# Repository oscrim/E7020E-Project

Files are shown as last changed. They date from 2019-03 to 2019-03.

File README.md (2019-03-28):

# E7020E-Project

# E-Toaster
Design and build a PCB to upgrade a toaster to an e-Toaster !

# Prerequisites 

* Archlinux
* Visual studio

# Implementation

For the software part we will use RUST to program the MCU.
Build with :
* Cargo
* OpenOCD

# Components

## General
* 1: Nucleo board to program our own board
* 1: USB Mini-B connector
* 1: bluetooth sensor RN 42 Series Class 2
* 1: STM32F411RET6 MCU
* 1: LM1117IMP-ADJ voltage converter
* 3: 6pins header
* 1: temp sensor LMT84
* 1: LCD screen EA DOGS102W-6
* 2: red LEDs
* 1: green LED
* 2: pushbuttons
* 2: transistors
* 1: relay 5V-230V

## Capacitors
* 2: 4.7u
* 12:  100n
* 5:   1u
* 2:   18p
* 1:   0.01u
* 2:   10u polarized

## Resistors
* 2:            4.7k
* 3:   10k
* 5:   100
* 1:   5k
* 2:   470
* 4:   3.3k
* 2:   1k
* 1:   820
* 1:   160

# Authors 

* **SCHRUB Valentin** - Hardware design and realization.

* **ROMARY Lucas** - Hardware design and realization.

* **FRISENSTAM Carl** - Software implementation.

* **RIMSBY Oscar** - Software implementation.

# Grades 

**Grade 3**:
Implement LED, push button, temperature sensor and LCD screen.

**Grade 4**:
Implement Bluetooth functionality. Write software to enable remote start of toaster. Enable LCD screen to display relevant information.

**Grade 5**:
Extend functionality of LCD screen. Additional information to be displayed. Improve remote functionality? Mobile application.

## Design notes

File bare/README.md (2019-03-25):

# `app`

> Examples and exercises for the Nucleo STM32F401re/STM32F11re devkits.

---

## Dependencies

- Rust 1.32, or later.

- `rust-std` components (pre-compiled `core` crate) for the ARM Cortex-M
  targets. Run:

``` console
$ rustup target add thumbv7em-none-eabihf
```

- For programming (flashing) and debugging
  - `openocd` (install using your package manager)
  - `arm-none-eabi` toolchain (install using your package manager). In the following we refer the `arm-none-eabi-gdb` as just `gdb` for brevity.

- `st-flash` (for low level access to the MCU flash)
- `itmdump` (for ITM trace output)
- `vscode` and `cortex-debug` (optional for an integrated debugging experience)

* https://marketplace.visualstudio.com/items?itemName=marus25.cortex-debug

---

## Examples

---

### Hello World! Building and Debugging an Application

1. Connect your devkit using USB. To check that it is found you can run:

``` console
$ lsusb
...
Bus 001 Device 004: ID 0483:374b STMicroelectronics ST-LINK/V2.1
...
```

(Bus/Device/ID may vary.)

2. In a terminal in the `app` folder run:

``` console
$ cargo build --example hello
$ openocd -f openocd.cfg
...
Info : Listening on port 6666 for tcl connections
Info : Listening on port 4444 for telnet connections
Info : clock speed 2000 kHz
Info : STLINK V2J20M4 (API v2) VID:PID 0483:374B
Info : Target voltage: 3.254773
Info : stm32f4x.cpu: hardware has 6 breakpoints, 4 watchpoints
Info : Listening on port 3333 for gdb connections
```

`openocd` should connect to your target using the `stlink` programmer (onboard your Nucleo devkit). See the `Trouble Shooting` section if you run into trouble. 

3. In another terminal (in the same `app` folder) run:

``` console
$ arm-none-eabi-gdb target/thumbv7em-none-eabihf/debug/examples/hello -x openocd.gdb
```

This starts gdb with `file` being the `hello` (elf) binary, and runs the `openocd.gdb` script, which loads (flashes) the binary to the target (our devkit). The script connects to the `openocd` server, sets `breakpoint`s at `main` (as well as some exception handlers, more on those later), enables `semihosting`, loads the binary and finally runs the first intsruction (`stepi`).

4. You can now continue debugging of the program:

``` console
(gdb) c
Continuing.

Breakpoint 3, main () at examples/hello.rs:13
13          hprintln!("Hello, world!").unwrap();
```

The `cortex-m-rt` run-time initializes the system and your global variables (in this case there are none). After that it calls the `[entry]` function. Here you hit a breakpoint.

5. You can contine debugging:

``` console
(gdb) c
Continuing.
halted: PC: 0x08000608
```

At this point, the `openocd` terminal should read:

``` console
Info : halted: PC: 0x08000608
Hello, world!
```

Your program is now stuck in an infinite loop (doing nothing).

6. Press `CTRL-c` in the `gdb` terminal:

``` console
Program received signal SIGINT, Interrupt.
0x08000624 in main () at examples/hello.rs:14
14          loop {}
(gdb)
```

You have now compiled and debugged a minimal Rust `hello` example. `gdb` is a very useful tool so lookup some tutorials/docs (e.g., https://sourceware.org/gdb/onlinedocs/gdb/), a Cheat Sheet can be found at https://darkdust.net/files/GDB%20Cheat%20Sheet.pdf.

---

### ITM Tracing

The `hello.rs` example uses the `semihosting` interface to emit the trace information (appearing in the `openocd` terminal). The drawback is that `semihosting` is incredibly slow as it involves a lot of machinery to process each character. (Essentially, it writes a character to a given position in memory, runs a dedicated break instruction, `openocd` detecects the break, reads the character at the given postition in memory and emits the character to the console.)

A better approach is to use de bultin in ITM (Instrumentation Trace Macrocell), designed to more efficently implement tracing. The onboard `stlink` programmer can put up to 4 characters into an ITM package, and transmit that to the host (`openocd`). `openocd` can process the incoming data and send it to a file or FIFO queue. The ITM package stream needs to be decoded (header + data). To this end we use the `itmdump` tool.

In a separate terminal:

``` console
$ mkfifo /tmp/itm.log
$ itmdump -f /tmp/itm.log -F
```

Now you can compile and run the `itm.rs` application using the same steps as the `hello` program. In the `itmdump` console you should now have the trace output.

``` console
$ mkfifo /tmp/itm.log
$ itmdump -f /tmp/itm.log -F
Hello, world!
```

Under the hood there is much less overhead, the serial transfer rate is set to 2MBit in between the ITM (inside of the MCU) and `stlink` programmer (onboard the Nucleo devkit). So in theory we can transmit some 200kByte/s data over ITM. However, we are limited by the USB interonnection and `openocd` to recieve and forward packages.

The `stlink` programmer, buffers packages but has limited buffer space. Hence in practise, you should keep tracing to short messages, else the buffer will overflow. See trouble shooting section if you run into trouble.

---

### Rust `panic` Handling

The `rust` compiler statically analyses your code, but in cases some errors cannot be detected at compile time (e.g., array indexing out of bounds, division by zore etc.). The `rust` compiler generates code checking such faults at run-time, instead of just crashing (or even worse, continuing with faulty/undefined values like a `C` program would) . A fault in Rust will render a `panic`, whith an associated error message (useful to debugging the application). We can choose how such `panic`s should be treated, e.g., transmitting the error message using `semihosting`, `ITM`, some other channel (e.g. a serial port), or simply aborting the program.

The `panic` example demonstrates some possible use cases.

The `openocd.gdb` script sets a breakpoint at `rust_begin_unwind` (a function in the  `rust core` library, used to recover errors.)

When running the example (see above howto compile and run), the `gdb` terminal will show:

``` console
...
Breakpoint 2, main () at examples/panic.rs:27
27          panic!("Oops")
(gdb) c
Continuing.
halted: PC: 0x08000404

Breakpoint 1, rust_begin_unwind (_info=0x20017fb4)
    at /home/pln/.cargo/registry/src/github.com-1ecc6299db9ec823/panic-halt-0.2.0/src/lib.rs:33
33              atomic::compiler_fence(Ordering::SeqCst);
(gdb) p *_info
$1 = core::panic::PanicInfo {payload: core::any::&Any {pointer: 0x8000760 <.Lanon.21a036e607595cc96ffa1870690e4414.142> "\017\004\000", vtable: 0x8000760 <.Lanon.21a036e607595cc96ffa1870690e4414.142>}, message: core::option::Option<&core::fmt::Arguments>::Some(0x20017fd0), location: core::panic::Location {file: <error reading variable>, line: 27, col: 5}}
```

Here `p *_info` prints the arument to `rust_begin_unwind`, at the far end you will find `line: 27, col 5`, which correstponds to the source code calling `panic("Ooops")`. (`gdb` is not (yet) Rust aware enough to figure out how the `file` field should be interpreted, but at least we get some useful information).

Alternatively we can trace the panic message over `semihosting` (comment out `extern crate panic_halt` and uncomment `extern crate panic_semihosting`).

The `openocd` console should now show:

``` console
Info : halted: PC: 0x080011a0
panicked at 'Oops', examples/panic.rs:27:5
```

Under the hood, this approach involves *formatting* of the panic message, which implementation occupies a bit of flash memory (in our case we have 512kB so plenty enough, but for the smallest of MCUs this may be a problem). Another drawback is that it requires a debugger to be connected and active.

Another alternative is to use ITM (uncomment `extern crate panic_itm`), this is faster, but be aware, the message may overflow the `ITM` buffer, so it may be unreliable. Also it assumes, that the ITM stream is actively monitored.

A third alternative would be to store the panic message in some non-volatile memory (flash, eeprom, etc.). This allows for true post-mortem debugging of a unit put in production. This approach is used e.g. in automotive applications where the workshop can read-out error codes of your vehicle.

---

### Exception Handling and Core Peripheral Access

The ARM Cortex-M processors features a set of *core* peripherpherals and *exception* handlers. These offer basic functionality independent of vendor (NXP, STM, ...). The `SysTick` perihperal is a 24-bit countdown timer, that raises a `SysTick` exception when hitting 0 and reloads the set value. Seen as a real-time system, we can dispatch the `SysTick` task in a periodic fashion (without accumulated drift under some additional constraints).

In the `exception.rs` example  a `.` is emitted by the `SysTick` handler using `semihosting`. Running the example should give you a periodic updated of the `openocd` console.

The `exception_itm.rs` and `exception_itm_raw.rs` uses the ITM instead. The difference is the way
they gain access to the `ITM` periphereal. In the first case we *steal* the whole set of core peripherals (stealing works only in `--release` mode), while the in the second case we use *raw* pointer access to the `ITM`. In both cases, the code is *unsafe*, as there is no guarantee that other tasks may access the peripheral simultaneously (causing a conflict/race). Later we will see how the concurrency problem is solved in RTFM to offer safe access to peripherals.

---

### Crash - Analysing the Exception Frame

In case the execution of an intstruction fails, a `HardFault` exception is raised by the hardware, and the `HardFault` handler is executed. We can define our own handler as in example `crash.rs`. In `main` we attempt to read an illegal address, causing a `HardFault`, and we hit a breakpoint (`openocd.gdb` script sets a breakbpoint at the `HardFualt` handler). From there you can print the exception frame, reflecting the state of the MCU when the error occured. You can use `gdb` to give a `back trace` of the call-stack leading up to the error. See the example for detailed information.

---

### Device Crates and System View Descriptions (SVDs)

Besides the ARM provided *core* peripherals the STM32F401re/STM32F411re MCUs has numerous vendor specific peripherals (GPIOs, Timers, USARTs etc.). The vendor provides a System View Description (SVD) specifying the register block layouts (fields, enumerated values, etc.). Using the `svd2rust` tool we can derive a `Peripheral Access Crate` (PAC) providing an API for the device that allow us to access each register according to the vendors specification. The `device.rs` example showcase how a PAC for the  STM32F401re/STM32F411re MCUs can be added. (These MCUs have the same set of peripherals, only the the maximum clock rating differs.) Here we use the STM32F413 as that covers the STM32F401/411/413 devices.

The example output a `.` each second over `semihosting` and `ITM`.

Looking at the `Corgo.toml` file we find:

``` toml
[package]
authors = ["Per Lindgren <per.lindgren@ltu.se>"]
edition = "2018"
readme = "README.md"
name = "app"
version = "0.1.0"

[dependencies]
cortex-m-rt = "0.6.7"
cortex-m-semihosting = "0.3.2"

# panic-abort = "0.3.1" # requires nightly toolchain
panic-halt = "0.2.0"
panic-semihosting = "0.5.1"
panic-itm = "0.4.0"

bare-metal = "0.2.4"
nb = "0.1.1"
heapless = "0.4.1"

[dependencies.cortex-m-rtfm]
version = "0.4.0"
optional = true

[dependencies.cortex-m]
version = "0.5.8"
features = ["inline-asm"] # <- currently requires nightly compiler

# Uncomment for the allocator example.
# alloc-cortex-m = "0.3.5"

[dependencies.stm32f4]
version = "0.5.0"
features = ["stm32f413", "rt"]
optional = true

[dependencies.stm32f4xx-hal]
git = "https://github.com/stm32-rs/stm32f4xx-hal.git"
version = "0.2.8"
features = ["stm32f413", "rt"]
optional = true

[features]
pac = ["stm32f4"]
hal = ["stm32f4xx-hal"]
rtfm = ["cortex-m-rtfm"]
rtfm-tq = ["cortex-m-rtfm/timer-queue"]

# this lets you use `cargo fix`!
[[bin]]
name = "app"
test = false
bench = false

[profile.release]
incremental = false # disable incremental build to allow lto on nightly
codegen-units = 1   # better optimizations
debug = true        # symbols are nice and they don't increase the size on Flash
lto = true          # better optimizations
```

We compile `stm32f4` (a generic library for all STMF4 MCUs) with `features = ["stm32f413", "rt"]`, which indicates the specific MCU with `rt` (run-time support) enabled. By having the PAC as an optional dependency, we did not need to compile it (unless we need it, and as you might have experienced already compiling the PAC takes a bit of time to compile initially). (An SVD file is typically > 50k lines, amounting to the same (or more) lines of Rust code.)

---

### Hardware Abstraction Layer

For convenience common functionality can be implemented for a specific MCU (or family of MCUs). The `stm32f4xx-hal` is a Work In Progress, implementing a Hardware Abstraction Layer (hal) for the `stm32f4` family. It implements the `https://crates.io/search?q=embedded-hal` serial trait (interface), to read and write single bytes over a serial port. However, setting up communication is out of scope for the `embedded-hal`.

The `serial.rs` example showcase a simple echo application,
repeating back incoming data over a serial port (byte by byte). You will also get trace output over the ITM.

Looking closer at the example, `rcc` is a *singleton* (`constrain` consumes the `RCC` and returns a singleton. The `freeze` consumes the  singleton (`rcc`) and sets the MCU clock tree according to the (default) `cfgr`. (Later in the exercises you will change this.)

This pattern ensures that the clock configuration will remain unchanged (the `freeze` function cannot be called again, as the `rcc` is consumed, also you cannot get a new `rcc` as the `RCC` was consumed by `contstrain`).

Why is this important you may ask? Well, this *pattern* allows the compiler to check and ensure that your code (or some library that you use) does not make changes to the system (in this case the clocking), wich reduces the risk of errors and improves robustness.

Similarly, we `split` the `GPIOA` into its parts (pins), and select the operating mode to `af7` for `tx` (the transmit pin `pa2`), and `rx` (the receive pin `pa3`). For details see, RM0368, figure 17 (page 151), and table 9 in STM32F401xD STM32F401xE. The GPIO pins `pa2` and `pa3` are (by default) connected to the `stlink` programmer, see section 6.8 of the Nucleo64 user manual `UM1724`. When the `stlink` programmer is connected to a linux host, the device `\dev\ttyACM0` appears as a *virtual com port* (connected to `pa2`/`pa3` by default).

Now we can call `Serial::usart2` to setup the serial communication, (according to table 9 in STM32F401xD STM32F401xE documentation it is USART2).

Following the *singleton* pattern it consumes the `USART2` peripheral (to ensure that only one configuration can be active at any time). The second parameter is the pair of pins `(tx, px)` that we setup earlier.
The third parameter is the USART configuration. By defualt its set to 8 bit data, and one stop bit. We set the baudrate to 115200. We also pass the `clocks` (holding information about the MCU clock setup).

At this point `tx` and `rx` is owned by `serial`. We can get access to them again by `serial.split()`.

In the loop we match on the result of `block!(rx.read())`. `block!` repeatedly calls `rx.read()` until ether a byte is received or an error returned. In case `rx.read()` succeeded, we trace the received byte over the ITM, and echo it by `tx.write(byte)`, ignoring the result (we just assume sending will always succeed). In case `rx.read` returned with an error, we trace the error message.

As the underlying hardware implementation buffers only a single byte, the input buffer may overflow (resulting in `tx.read` returning an error).

You can now compile and run the example. Start `moserial` (or some other serial communication tool), connect to `/dev/ttyACM0` with 115200 8N1). Now write a single character `a` in the `Outgoing` pane, followed by pressing <Enter>. You should receive back an `a` from the target. In the ITM trace output you should see:

``` console
[2019-01-08T10:31:36.867Z]   Ok 97. 
```

Depending if <Enter> was encoded as CR+LF, CR, LF, TAB, ... you will get additional bytes sent (and received). Try sending multiple characters at once, e.g. `abcd`, you will see that the you well get a buffer overflow.

This is an example of a bad programming pattern, typically leading to serious problems in (real-time) embedded programming (so it takes more than just Rust to get it right). Later in the exercises we will see how better patterns can be adopted.

---

### RTFM Blinky

No example suit is complete without the mandatory `blinky` demo, so here we go! The exampe `rtfm_blinky.rs` showcase the simplicity of using the RTFM framework.

An application using RTFM is defined using the `app` attribute, specifying the target PAC.

- The `static mut` section defines the shared resources. In this example we need to access the `GPIOA` in the `SysTick` exception handler. Initially all resources are delegated to the `init` task (running before the system goes live).

- In `init` we:
  - configure the `SysTick` exception/task to be triggered periodically (each second),- configure the `RCC` (enabling the `GPIOA` peripheral),
  - configure the `PA5` pin (connected to the Green LED on the Nucleo) as an output, and finally
  - delegate access to `GPIO` as a "late" resource.

- The `#[exception (resources = [GPIOA])]` attribute enables access to the `GPIOA` peripheral for the `SysTick` exception/task. (Resource access goes through `resources.<RESOURCE>`.)

- In `SysTick` we define a task local resource `TOGGLE` to hold the current state, and we set/clear the `PA5` pin correspondingly. (The `bs5` field sets the `PA5` high, while `br5` clears the corresponding bit controlling the led.) Finnally the `TOGGLE` state is inverted.

Notice here, under the hood the RTFM framework analyses the `app` and concludes that `TOGGLE` and `GPIOA` are accessible (in scope) for `SysTick` exclusively, so we safely (without running any risk of race conditions) access the resources directly.

Side note: Accessing a resource shared with a higher priority task, requires the user to lock the resource in order to guarantee race-free access. For further information, see the RTFM API documentation and book, cf. `cortex-m-rtfm`.

``` rust
use rtfm::app;

#[app(device = stm32f4::stm32f413)]
const APP: () = {
    // late resorce binding
    static mut GPIOA: GPIOA = ();

    // init runs in an interrupt free section
    #[init]
    fn init() {
        // configures the system timer to trigger a SysTick exception every second
        core.SYST.set_clock_source(SystClkSource::Core);
        core.SYST.set_reload(16_000_000); // period = 1s
        core.SYST.enable_counter();
        core.SYST.enable_interrupt();

        // power on GPIOA, RM0368 6.3.11
        device.RCC.ahb1enr.modify(|_, w| w.gpioaen().set_bit());
        // configure PA5 as output, RM0368 8.4.1
        device.GPIOA.moder.modify(|_, w| w.moder5().bits(1));

        // pass on late resources
        GPIOA = device.GPIOA;
    }

    #[exception (resources = [GPIOA])]
    fn SysTick() {
        static mut TOGGLE: bool = false;

        if *TOGGLE {
            resources.GPIOA.bsrr.write(|w| w.bs5().set_bit());
        } else {
            resources.GPIOA.bsrr.write(|w| w.br5().set_bit());
        }

        *TOGGLE = !*TOGGLE;
    }
};
```

---

## Trouble Shooting

Working with embedded targets involves a lot of tooling, and many things can go wrong.

---

### `openocd` fails to connect

If you end up with a program that puts the MCU in a bad state.

- Hold the `RESET` button (black), while starting `openocd`. If that does not work, disconnect the USB cable, hold the `RESET` button, re-connect the USB, start `openocd` then then let go of the button.

- However even a reset might not help you. In that case you can erase the flash memory. `st-flash` connects to the target directly (bypassing `gdb` and `openocd`) and hence more likely to get access to the target even if its in a bad state.

``` console
> st-flash erase
```

- Make sure that the `st-link` firmare is up to date, you can use the java application: https://my.st.com/content/my_st_com/en/products/development-tools/software-development-tools/stm32-software-development-tools/stm32-programmers/stsw-link007.license=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, to check/update the firmware. (Current verison is 2.33.25)

---

### `gdb` fails to connect

`openocd` acts as a *gdb server*, while `gdb` is a *gdb client*. By default they connect over port `:3333` (: indicates that the port is on the *localhost*, not a remote connection). In cases you might have another `gdb` connection blocking the port.

``` console
$ ps -all
F S   UID   PID  PPID  C PRI  NI ADDR SZ WCHAN  TTY          TIME CMD
0 S  1000  5659  8712  0  80   0 -  6139 -      pts/1    00:00:28 openocd
0 S  1000  7549 16215  0  80   0 - 25930 se_sys pts/4    00:00:00 arm-none-eabi-g
...
```

In this case you can try killing `gdb` by:

``` console
$ kill -9 7549
```

or even

``` console
$ killall -9 arm-none-eabi-g
```

Notice, the process name is truncated for some reason...

If this did not help you can check if some other client has aquired the port, and kill the intruder accordingly. (In this case it was the gdb process so the above method would have worked, but in general it could be another process blocking the port.)

``` console
$ lsof -i :3333
COMMAND    PID USER   FD   TYPE DEVICE SIZE/OFF NODE NAME
openocd   5659  pln   12u  IPv4 387143      0t0  TCP localhost:dec-notes (LISTEN)
openocd   5659  pln   13u  IPv4 439988      0t0  TCP localhost:dec-notes->localhost:59560 (ESTABLISHED)
arm-none- 7825  pln   14u  IPv4 442734      0t0  TCP localhost:59560->localhost:dec-notes (ESTABLISHED)
$ kill -9 7825
```

---

### `itmdump` no tracing or faulty output

There can be a number of reasons ITM tracing fails.

- The `openocd.gdb` script enables ITM tracing assuming the `/tmp/itm.log` and `itmdump` has been correctly setup before `gdb` is launched (and the script run). So the first thing is to check that you follow the sequence suggested above.

- `openocd.gdb`sets enables ITM tracing by:

``` txt
# 16000000 must match the core clock frequency
monitor tpiu config internal /tmp/itm.log uart off 16000000
monitor itm port 0 on
```

The transfer speed (baud rate) is automatically negotiated, however you can set it explicitly (maximum 2000000).  

``` txt
monitor tpiu config internal /tmp/itm.log uart off 16000000 2000000
```

You may try a lower value.

- The `stm32f401re/stm32f411re` defaults to 16000000 (16MHz) as the core clock frequency, based on an internal oscillator. If your application sets another core clock frequency the `openocd.gdb` script (`tpiu` setting) must be changed accordingly.

- `openocd` implements a number of `events` which might be called by `gdb`, e.g.:

``` console
(gdb) monitor reset init
adapter speed: 2000 kHz
target halted due to debug-request, current mode: Thread
xPSR: 0x01000000 pc: 0x08001298 msp: 0x20018000, semihosting
adapter speed: 8000 kHz
```

This invokes the `init` event, which sets the core clock to 64MHz. If you intend to run the MCU at 64MHz (using this approach), ITM will not work unless the `tpiu` setting matches 64MHz.

If you on the other hand want to use `monitor reset init` but not having the core clock set to 64MHz, you can use a custom `stlink.cfg` (instead of the one shipped with `openocd`). The original looks like this:

``` txt
...
$_TARGETNAME configure -event reset-init {
	# Configure PLL to boost clock to HSI x 4 (64 MHz)
	mww 0x40023804 0x08012008   ;# RCC_PLLCFGR 16 Mhz /8 (M) * 128 (N) /4(P)
	mww 0x40023C00 0x00000102   ;# FLASH_ACR = PRFTBE | 2(Latency)
	mmw 0x40023800 0x01000000 0 ;# RCC_CR |= PLLON
	sleep 10                    ;# Wait for PLL to lock
	mmw 0x40023808 0x00001000 0 ;# RCC_CFGR |= RCC_CFGR_PPRE1_DIV2
	mmw 0x40023808 0x00000002 0 ;# RCC_CFGR |= RCC_CFGR_SW_PLL

	# Boost JTAG frequency
	adapter_khz 8000
}
```

The clock configuration can be commented out:

``` txt
...
$_TARGETNAME configure -event reset-init {
	# # Configure PLL to boost clock to HSI x 4 (64 MHz)
	# mww 0x40023804 0x08012008   ;# RCC_PLLCFGR 16 Mhz /8 (M) * 128 (N) /4(P)
	# mww 0x40023C00 0x00000102   ;# FLASH_ACR = PRFTBE | 2(Latency)
	# mmw 0x40023800 0x01000000 0 ;# RCC_CR |= PLLON
	# sleep 10                    ;# Wait for PLL to lock
	# mmw 0x40023808 0x00001000 0 ;# RCC_CFGR |= RCC_CFGR_PPRE1_DIV2
	# mmw 0x40023808 0x00000002 0 ;# RCC_CFGR |= RCC_CFGR_SW_PLL

	# Boost JTAG frequency
	adapter_khz 8000
}
```

You can start `openocd` to use these (local) settings by:

``` console
$ openocd -f stlink.cfg -f stm32f4x.cfg
```

A possible advantege of `monitor reset init` is that the `adapter speed` is set to 8MHz, which at least in theory gives better transfer rate between `openocd` and the `stlink` programmer (default is 2MBit). I'm not sure the improvement is noticable.

- ITM buffer overflow

In case the ITM buffer is saturated, ITM tracing stops working (and might be hard to recover). In such case:

  1. correct and recompile the program,

  2. erase the flash (using `st-flash`), 

  3. power cycle the Nucleo (disconnect-and-re-connect),

  4. remove/re-make fifo, and finally re-start `openocd`/`gdb`.
  
This ensures 1) the program will not yet again overflow the ITM buffer, 2) the faulty program is gone (and not restarted accidently on a `RESET`), 3) the programmer firmware is restarted and does not carry any persistent state, notice a `RESET` applies only to the target, not the programmer, so if the programmer crashes it needs to be power cycled), 4) the FIFO `/tmp/itm.log`, `openocd` and `gdb` will have fresh states.

- Check/udate the Nucleo `st-link` firmware (as mentioned above).

---

## Visual Studio Code

`vscode` is highly configurable, (keyboard shortcuts, keymaps, plugins etc.) There is Rust support through the `rls-vscode` plugin (https://github.com/rust-lang/rls-vscode).

It is possible to run `arm-none-eabi-gdb` from within the `vscode` using the `cortex-debug` plugin (https://marketplace.visualstudio.com/items?itemName=marus25.cortex-debug).

For general informaiton regarding debugging in `vscode`, see https://code.visualstudio.com/docs/editor/debugging.

Some useful (default) shortcuts:

- `CTRL+SHIFT+b` compilation tasks, (e.g., compile all examples `cargo build --examples`). Cargo is smart and just re-compiles what is changed.

- `CTRL+SHIFT+d` debug launch configurations, enter debug mode to choose a binary (e.g., `itm 64MHz (debug)`)

- `F5` to start. It will open the `cortex_m_rt/src/lib.rs` file, which contains the startup code. From there you can continue `F5` again.
- `F6` to break. The program will now be in the infinite loop (for this example). In general it will just break wherever the program counter happens to be.
- You can view the ITM trace in the `OUTPUT` tab, choose the dropdown `SWO: ITM [port 0, type console]`. It should now display:

``` txt
[2019-01-02T21:35:26.457Z]   Hello, world!
```

- `SHIFT-F5` shuts down the debugger.

You may step, view the current context `variables`, add `watches`, inspect the `call stack`, add `breakpoints`, inspect `peripherals` and `registers`. Read more in the documentation for the plugin.

### Caveats

Visual Studio Code is not an "IDE", its a text editor with plugin support, with an API somewhat limiting what can be done from within a plugin (in comparison to Eclipse, IntelliJ...) regarding panel layouts etc. E.g., as far as I know you cannot view the `adapter output` (`openocd`) at the same time as the ITM trace, they are both under the `OUTPUT` tab. Moreover, each time you re-start a debug session, you need to re-select the `SWO: Name [port 0, type console]` to view the ITM output. There are some `hax` around this:

- Never shut down the debug session. Instead use the `DEBUG CONSOLE` (`CTRL+SHIFT+Y`) to get to the `gdb` console. This is not the *full* `gdb` interactive shell with some limitations (no *tab* completion e.g.). Make sure the MCU is stopped (`F6`). The console should show something like:

``` txt
Program
 received signal SIGINT, Interrupt.
0x0800056a in main () at examples/itm.rs:31
31	    loop {}
```

- Now you can edit an re-compile your program, e.g. changing the text:

> iprintln!(stim, "Hello, again!");

- In the `DEBUG CONSOLE`, write `load` press `ENTER` write `monitor reset init` press `ENTER`.

``` txt
load
{"token":97,"outOfBandRecord":[{"isStream":false,"type":"status","asyncClass":"download","output":[]}]}
`/home/pln/rust/app/target/thumbv7em-none-eabihf/debug/examples/itm' has changed; re-reading symbols.
Loading section .vector_table, size 0x400 lma 0x8000000
Loading section .text, size 0x10c8 lma 0x8000400
Loading section .rodata, size 0x2a8 lma 0x80014d0
Start address 0x8001298, load size 6000
Transfer rate: 9 KB/sec, 2000 bytes/write.

mon reset init
{"token":147,"outOfBandRecord":[],"resultRecords":{"resultClass":"done","results":[]}}
adapter speed: 2000 kHz
target halted due to debug-request, current mode: Thread 
xPSR: 0x01000000 pc: 0x08001298 msp: 0x20018000
adapter speed: 8000 kHz
```

- The newly compiled binary is now loaded and you can continue (`F5`). Switching to the `OUTPUT` window now preserves the ITM view and displays both traces:

``` txt
[2019-01-02T21:43:27.988Z]   Hello, world!
[2019-01-02T22:07:29.090Z]   Hello, again!
```

- Using the `gdb` terminal (`DEBUG CONSOLE`) from within `vscode` is somewhat instable/experimental. E.g., `CTRL+c` does not `break` the target (use `F6`, or write `interrupt`). The `contiune` command, indeed continues execution (and the *control bar* changes mode, but you cannot `break` using neither `F6` nor `interrupt`). So it seems that the *state* of the `cortex-debug` plugin is not correctly updated. Moreover setting breakpoints from the `gdb` terminal indeed informs `gdb` about the breakpoint, but the state in `vscode` is not updated, so be aware.

---

### Vscode Launch Configurations

Some example launch configurations from the `.vscode/launch.json` file:

``` json
 {
            "type": "cortex-debug",
            "request": "launch",
            "servertype": "openocd",
            "name": "itm 64Mhz (debug)",
            "executable": "./target/thumbv7em-none-eabihf/debug/examples/itm",
            "configFiles": [
                "interface/stlink.cfg",
                "target/stm32f4x.cfg"
            ],
            "postLaunchCommands": [
                "monitor reset init"
            ],
            "swoConfig": {
                "enabled": true,
                "cpuFrequency": 64000000,
                "swoFrequency": 2000000,
                "source": "probe",
                "decoders": [
                    {
                        "type": "console",
                        "label": "ITM",
                        "port": 0
                    }
                ]
            },
            "cwd": "${workspaceRoot}"
        },
        {
            "type": "cortex-debug",
            "request": "launch",
            "servertype": "openocd",
            "name": "hello 16Mhz (debug)",
            "executable": "./target/thumbv7em-none-eabihf/debug/examples/hello",
            "configFiles": [
                "interface/stlink.cfg",
                "target/stm32f4x.cfg"
            ],
            "postLaunchCommands": [
                "monitor arm semihosting enable"
            ],
            "cwd": "${workspaceRoot}"
        },

      {
            "type": "cortex-debug",
            "request": "launch",
            "servertype": "openocd",
            "name": "itm 16Mhz (debug)",
            "executable": "./target/thumbv7em-none-eabihf/debug/examples/itm",
            // uses local config files
            "configFiles": [
                "./stlink.cfg",
                "./stm32f4x.cfg"
            ],
            "postLaunchCommands": [
                "monitor reset init"
            ],
            "swoConfig": {
                "enabled": true,
                "cpuFrequency": 16000000,
                "swoFrequency": 2000000,
                "source": "probe",
                "decoders": [
                    {
                        "type": "console",
                        "label": "ITM",
                        "port": 0
                    }
                ]
            },
            "cwd": "${workspaceRoot}"
        },
```

We see some similarities to the `openocd.gdb` file, we don't need to explicitly connect to the target (that is automatic). Also launching `openocd` is automatic (for good and bad, its re-started each time). `postLaunchCommands` allows arbitrary commands to be executed by `gdb` once the session is up. E.g. in the `hello` case we enable `semihosting`, while in the `itm` case we run `monitor reset init` to get the MCU in 64MHz (first example) or 16MHz (third example), before running the application (continue). Notice the first example uses the "stock" `openocd` configuration files, while the third example uses our local configuration files (that does not change the core frequency).

---

## GDB Advanced Usage

There are numerous ways to automate `gdb`. Scripts can be run by the `gdb` command `source` (`so` for short). Scripting common tasks like setting breakpoints, dumping some memory region etc. can be really helpful.

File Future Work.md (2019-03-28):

# Future work

## Toaster

We're gonna replace the LED relay system with the real toaster. Before that we will need to focus on the safety, because it's 220V.

## Bluetooth

We're gonna finalize the bluetooth function. We will read the uart communication and start the toaster using that.

## Screen

Display meaningful informations. Use the push buttons to change the informations

## Software

Refactor the code, improve structure and readability. 

## PCB

Correct the PCB.

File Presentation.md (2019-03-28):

# Presentation of the project: E-Toaster

## Introduction

We wanted to upgrade a toaster to be able to start it via a bluetooth module. The idea was that the mcu pilot a relay that will enable the start of the toaster. We also wanted to make it display information with the use of a screen. The information we wanted to display were the temperature (get by a sensor) or a message when the bread is ready. We also tried to implement a system of LEDs to see when the bluetooth module or the toaster is working.

## Choice of the components

The choice of the components was made following our given budget and needs. We tried to keep low prices as much as possible. We also selected means of communication that we already knew, like SPI and UART. One of the criteria was also that the product has a good datasheet, which simplify a lot of the work.

## Design of the Kicad

We started to design the implementation of the essentials components, including the microcontroller, the voltage regulator system and the programmable pins. Then we added our own components. Finally we added some more backup pins and some testpoints to check is everything is working as intended.
We also added two buttons, one to reset the MCU and one to control the screen.

## Soldering

It was our first time trying to solder SMD components. We had to use our second board because of some problems on the first one (probably the MCU that died). We started by soldering the power system and checking if it was working as intented, to be sure to not damage anything again. Then everytime we soldered something, we used the testpoints to check if the connection was well made. The hardest thing to solder was the bluetooth module and it involved the use of the "SMD Rework Station".
At some point we had a problem with the usb connector. The print on our Kicad was reversed compared to the reality. It caused us to send 5V on the ground and vice-versa. So we had to use our backup pins to get the system working. 

## Use of the bluetooth module

We were able to communicate with the bluetooth module using a serial communication with a computer, only on Windows however. we could modify some parameters of it or simply send data to the MCU with an UART connection. We also implemented two LEDs, one green and one red. The green LED tells us if the module wait for a connection, is connected or is in control mode. The red LED lights up everytime we send a data to the MCU.

## Temperature sensor and ADC

Communicating with the temperature sensor was no problem and was done easily, what was more of a challenge was the ADC as the crate used didn't have the ADC component, this however turned out to be due to an outdated crate and updating it solved the issue. In the datasheet for the temperature sensor there was a formula for the conversion between millivolts and degrees Celcius

Eq

It was however not possible to do this kind of mathematics on the PCB since we are unable to use the standard libraries, therefore we had to approximate the conversion using a linear model instead which gave us.

Est

This is not perfect but it is close enough for the temperatures we have, we also decided that since some of the calculations will have too many decimals and we cant easily change the number of decimals we will round the temperatures to the closest integer

## Use of the relay

We wanted to use the relay to start the toaster when we want. For reasons of time and safety, we use the relay to power a LED with a 12V power supply. Except for the safety part, the method to control 12V or 230V is the same. We use a GPIO that control a transistor which will activate the relay.

## LCD

We decided to implement a lcd display that would show off some relevant information. We didnt have time to implement all the information to display however we did set up the screen and gathered relevant data so all you would have to do is print the correct letters. The screen operates over serial peripheral interface (SPI). This is done by just sending all the data to a mosi pin.

## Pushbutton

Lastly we decided to implement a pushbutton. This button, as it funcions currently, simply starts the simulated breadroasting. So when you click the button you get a loading screen basically which is supposed to sumbolize the breadroasting process. This could function as the start and stop button in a fully implemented version.

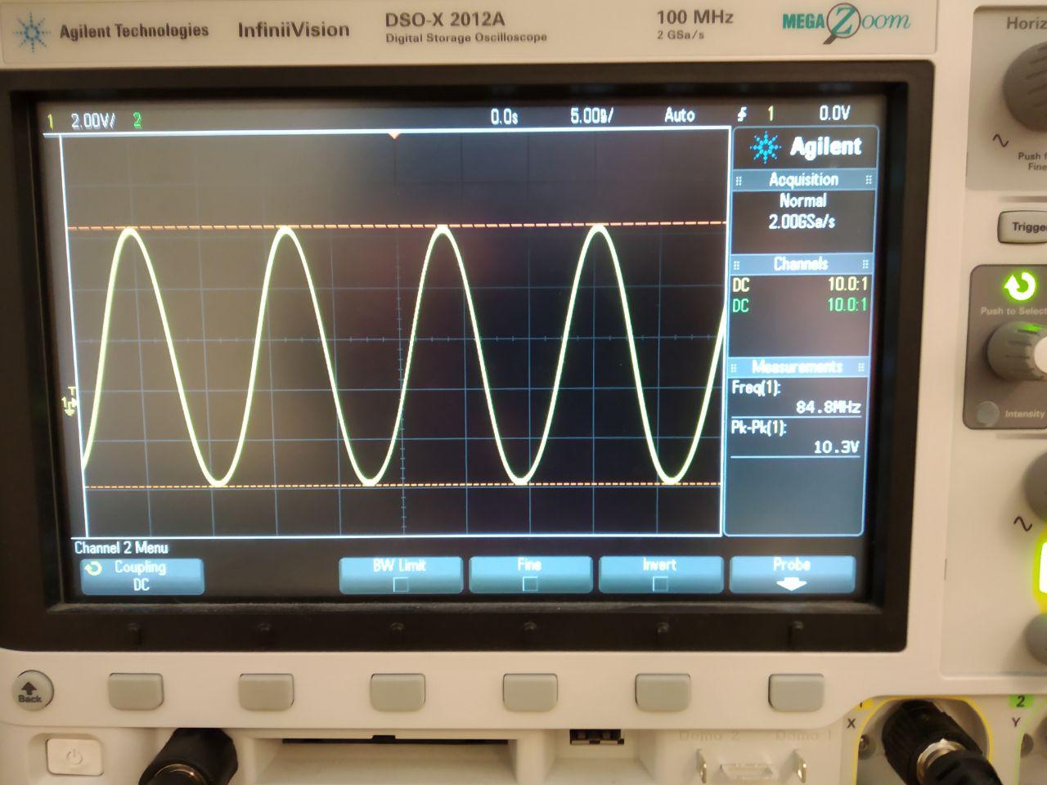
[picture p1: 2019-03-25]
bare/pictures/bare_7_84mhz_high_speed.jpg

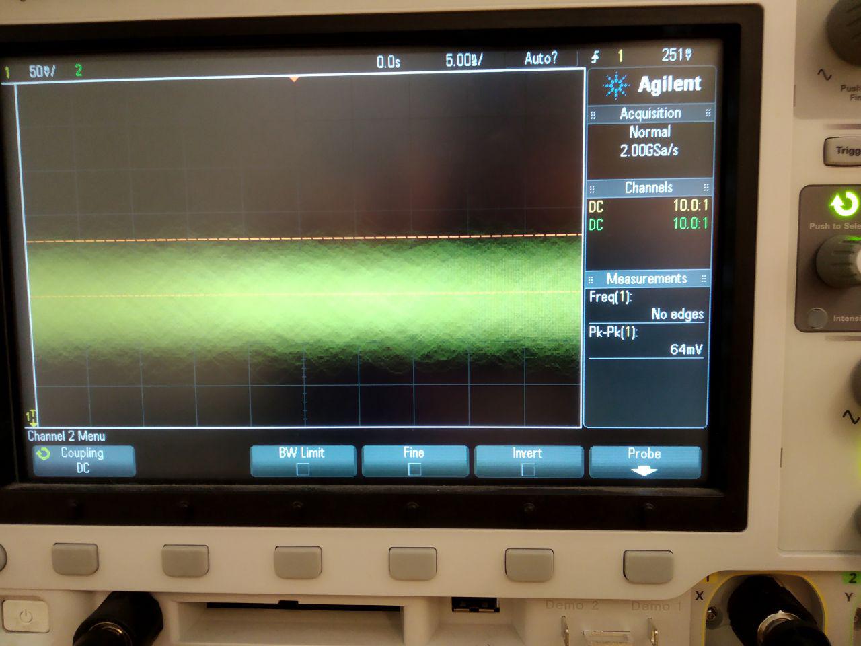
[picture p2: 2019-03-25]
bare/pictures/bare_7_84mhz_low_speed.jpg

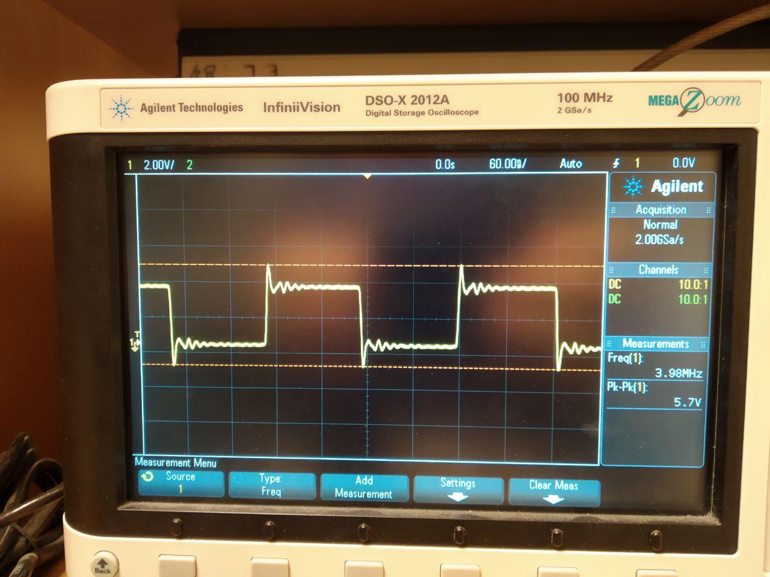
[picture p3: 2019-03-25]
bare/pictures/bare_6_16mhz_high_speed.jpg

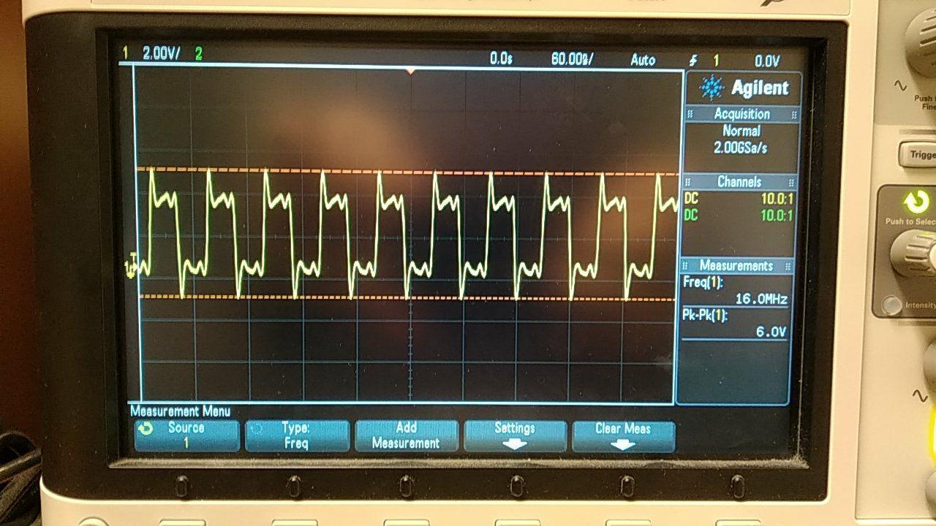
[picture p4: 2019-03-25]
bare/pictures/bare_6_64mhz_high_speed.jpg

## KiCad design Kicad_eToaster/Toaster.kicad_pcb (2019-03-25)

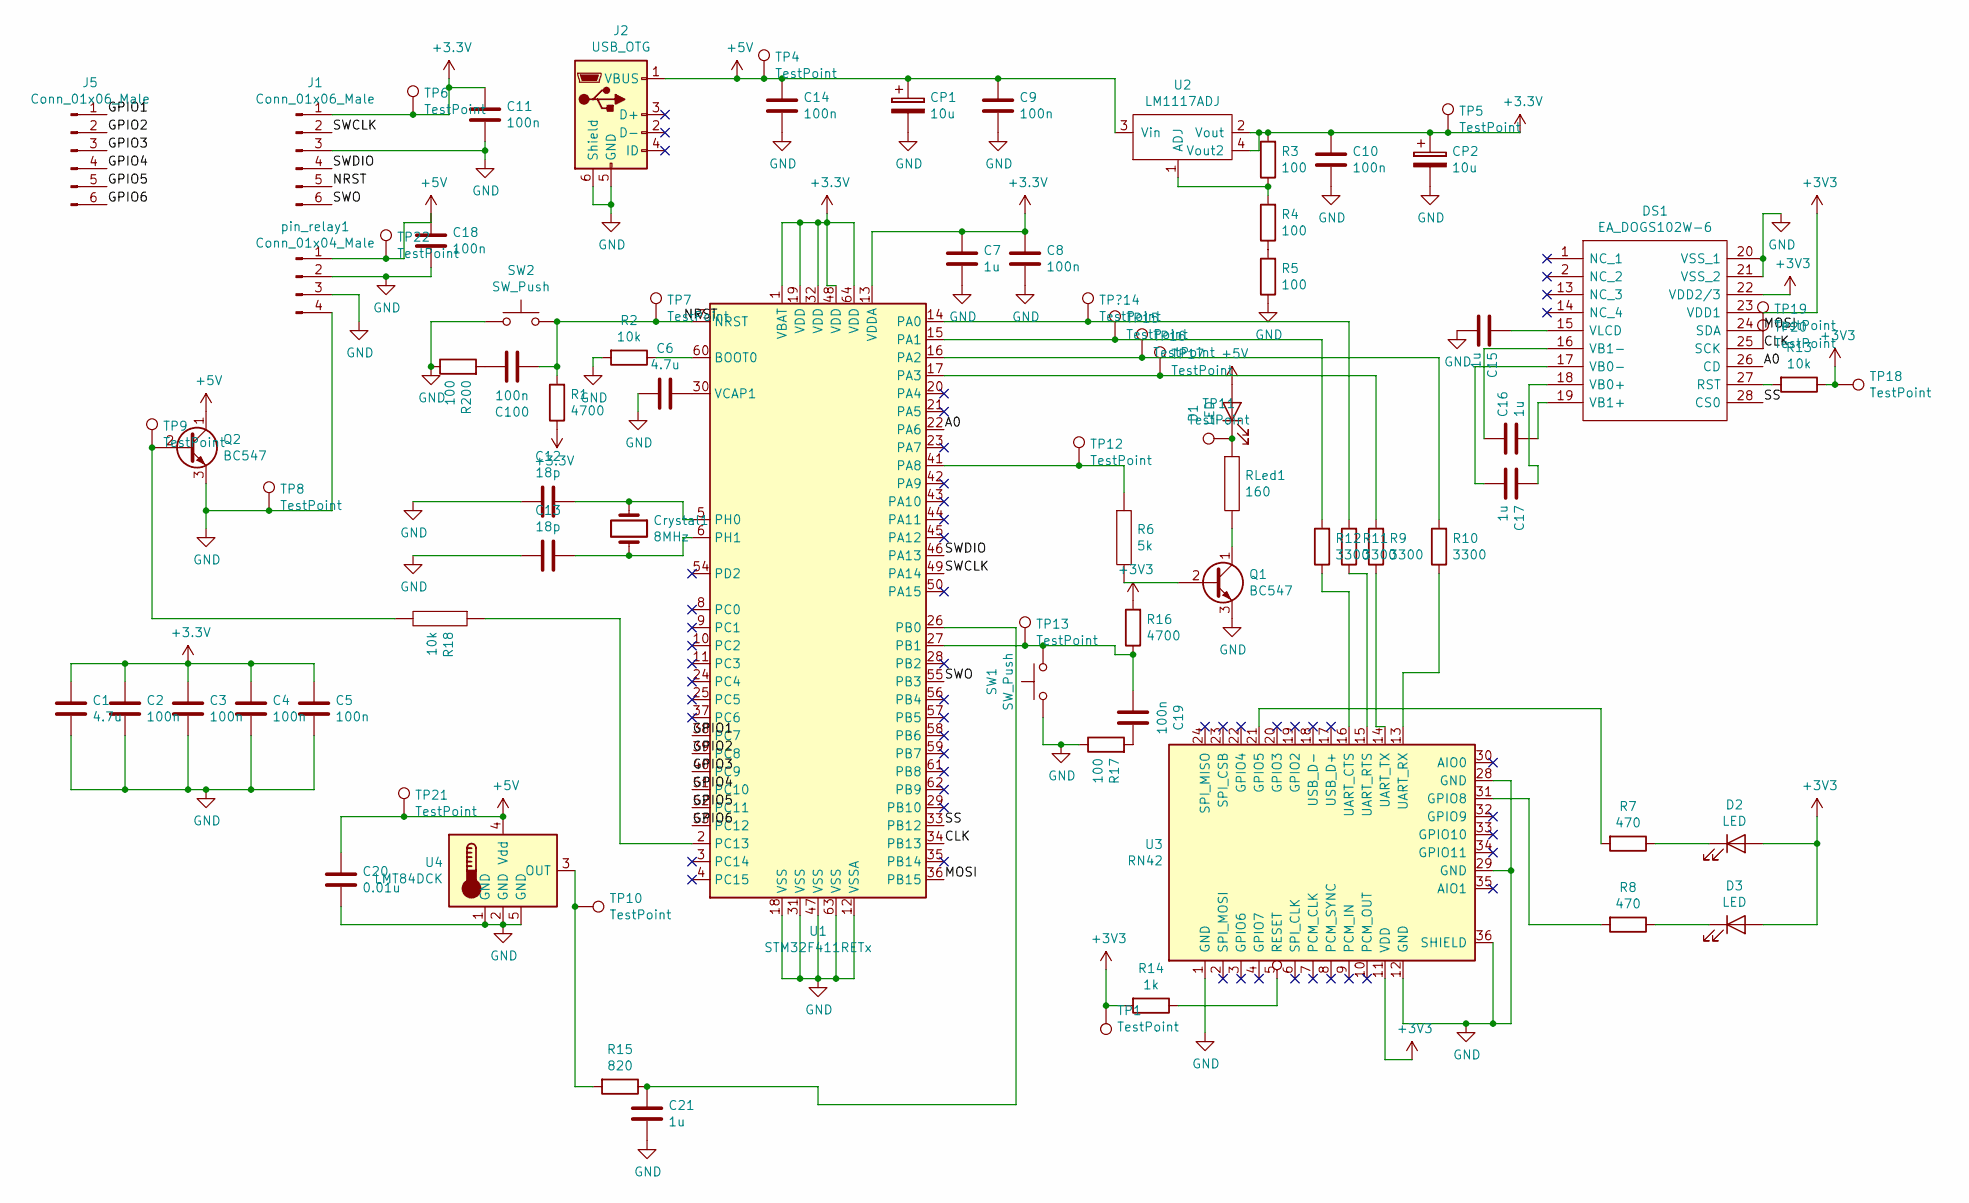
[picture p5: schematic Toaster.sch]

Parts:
C1, C6: 4.7u; C_0805_2012Metric_Pad1.15x1.40mm_HandSolder
C2, C3, C4, C5, C8, C9, C10, C11, C14, C18, C19, C100: 100n; C_0805_2012Metric_Pad1.15x1.40mm_HandSolder
C7, C15, C16, C17, C21: 1u; C_0805_2012Metric_Pad1.15x1.40mm_HandSolder
C12, C13: 18p; C_0805_2012Metric_Pad1.15x1.40mm_HandSolder
C20: 0.01u; C_0805_2012Metric_Pad1.15x1.40mm_HandSolder
CP1, CP2: 10u; CP_Radial_D5.0mm_P2.00mm
Crystal1: 8MHz; Crystal_SMD_HC49-SD_HandSoldering
D1, D2, D3: LED; LED_D5.0mm
DS1: EA_DOGS102W-6; EA-DOGS102W-6; Manufacturer_Part_Number EA DOGS102W-6; Mouser Part Number 790-EADOGS102W-6
J1, J5: Conn_01x06_Male; PinHeader_1x06_P2.54mm_Vertical
J2: USB_OTG; USB_Mini-B_AdamTech_MUSB-B5-S-VT-TSMT-1_SMD_Vertical
Q1, Q2: BC547; TO-92_Inline
R1, R16: 4700; R_0805_2012Metric_Pad1.15x1.40mm_HandSolder
R2, R13, R18: 10k; R_0805_2012Metric_Pad1.15x1.40mm_HandSolder
R3, R4, R5, R17, R200: 100; R_0805_2012Metric_Pad1.15x1.40mm_HandSolder
R6: 5k; R_0805_2012Metric_Pad1.15x1.40mm_HandSolder
R7, R8: 470; R_0805_2012Metric_Pad1.15x1.40mm_HandSolder
R9, R10, R11, R12: 3300; R_0805_2012Metric_Pad1.15x1.40mm_HandSolder
R14: 1k; R_0805_2012Metric_Pad1.15x1.40mm_HandSolder
R15: 820; R_0805_2012Metric_Pad1.15x1.40mm_HandSolder
RLed1: 160; R_0805_2012Metric_Pad1.15x1.40mm_HandSolder
SW1, SW2: SW_Push; SW_PUSH_6mm_H4.3mm
TP1, TP4, TP5, TP6, TP7, TP8, TP9, TP10, TP11, TP12, TP13, TP15, TP16, TP17, TP18, TP19, TP20, TP21, TP22: TestPoint; TestPoint_Pad_1.0x1.0mm
TP?14: TestPoint; TestPoint_Pad_1.0x1.0mm
U1: STM32F411RETx; LQFP-64_10x10mm_P0.5mm
U2: LM1117ADJ; SOT-223
U3: RN42
U4: LMT84DCK; SOT-353_SC-70-5_Handsoldering
pin_relay1: Conn_01x04_Male; FanPinHeader_1x04_P2.54mm_Vertical

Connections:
+5V: C9.2, C14.2, C18.2, C20.1, CP1.1, D1.2 (A), J2.1 (VBUS), Q2.1 (C), TP4.1, TP21.1, TP22.1, U2.3 (Vin), U4.4 (Vdd), pin_relay1.1
/A0: DS1.26 (CD), U1.22 (PA6)
/CLK: DS1.25 (SCK), TP20.1, U1.34 (PB13)
/GPIO1: J5.1, U1.38 (PC7)
/GPIO2: J5.2, U1.39 (PC8)
/GPIO3: J5.3, U1.40 (PC9)
/GPIO4: J5.4, U1.51 (PC10)
/GPIO5: J5.5, U1.52 (PC11)
/GPIO6: J5.6, U1.53 (PC12)
/MOSI: DS1.24 (SDA), TP19.1, U1.36 (PB15)
/NRST: C100.2, J1.5, R1.2, SW2.2, TP7.1, U1.7 (NRST)
/SS: DS1.28 (CS0), U1.33 (PB12)
/SWCLK: J1.2, U1.49 (PA14)
/SWDIO: J1.4, U1.46 (PA13)
/SWO: J1.6, U1.55 (PB3)
GND: C1.1, C2.1, C3.1, C4.1, C5.1, C6.1, C7.1, C8.1, C9.1, C10.1, C11.1, C12.2, C13.2, C14.1, C15.1, C18.1, C20.2, C21.2, CP1.2, CP2.2, DS1.20 (VSS_1), DS1.21 (VSS_2), J1.3, J2.5 (GND), J2.6 (Shield), Q1.3 (E), Q2.3 (E), R2.2, R5.1, R17.1, R200.1, SW1.1, SW2.1, TP8.1, U1.12 (VSSA), U1.18 (VSS), U1.31 (VSS), U1.47 (VSS), U1.63 (VSS), U3.1 (GND), U3.12 (GND), U3.28 (GND), U3.29 (GND), U3.36 (SHIELD), U4.1 (GND), U4.2 (GND), U4.5 (GND), pin_relay1.2, pin_relay1.3, pin_relay1.4
unnamed: C6.2, U1.30 (VCAP1)
unnamed: C12.1, Crystal1.1, U1.5 (PH0)
unnamed: C13.1, Crystal1.2, U1.6 (PH1)
unnamed: C15.2, DS1.15 (VLCD)
unnamed: C16.1, DS1.19 (VB1+)
unnamed: C16.2, DS1.16 (VB1-)
unnamed: C17.1, DS1.17 (VB0-)
unnamed: C17.2, DS1.18 (VB0+)
unnamed: C19.1, R17.2
unnamed: C19.2, R16.1, SW1.2, TP13.1, U1.27 (PB1)
unnamed: C21.1, R15.1, U1.26 (PB0)
unnamed: C100.1, R200.2
unnamed: D1.1 (K), RLed1.1, TP11.1
unnamed: D2.1 (K), R7.1
unnamed: D3.1 (K), R8.1
unnamed: DS1.27 (RST), R13.2
unnamed: Q1.1 (C), RLed1.2
unnamed: Q1.2 (B), R6.2
unnamed: Q2.2 (B), R18.2, TP9.1
unnamed: R2.1, U1.60 (BOOT0)
unnamed: R3.1, R4.2, U2.1 (ADJ)
unnamed: R4.1, R5.2
unnamed: R6.1, TP12.1, U1.41 (PA8)
unnamed: R7.2, U3.21 (GPIO5)
unnamed: R8.2, U3.31 (GPIO8)
unnamed: R9.1, U3.14 (UART_TX)
unnamed: R9.2, TP17.1, U1.17 (PA3)
unnamed: R10.1, U3.13 (UART_RX)
unnamed: R10.2, TP16.1, U1.16 (PA2)
unnamed: R11.1, U3.15 (UART_RTS)
unnamed: R11.2, TP?14.1, U1.14 (PA0)
unnamed: R12.1, U3.16 (UART_CTS)
unnamed: R12.2, TP15.1, U1.15 (PA1)
unnamed: R14.1, U3.5 (RESET)
unnamed: R15.2, TP10.1, U4.3 (OUT)
unnamed: R18.1, U1.2 (PC13)

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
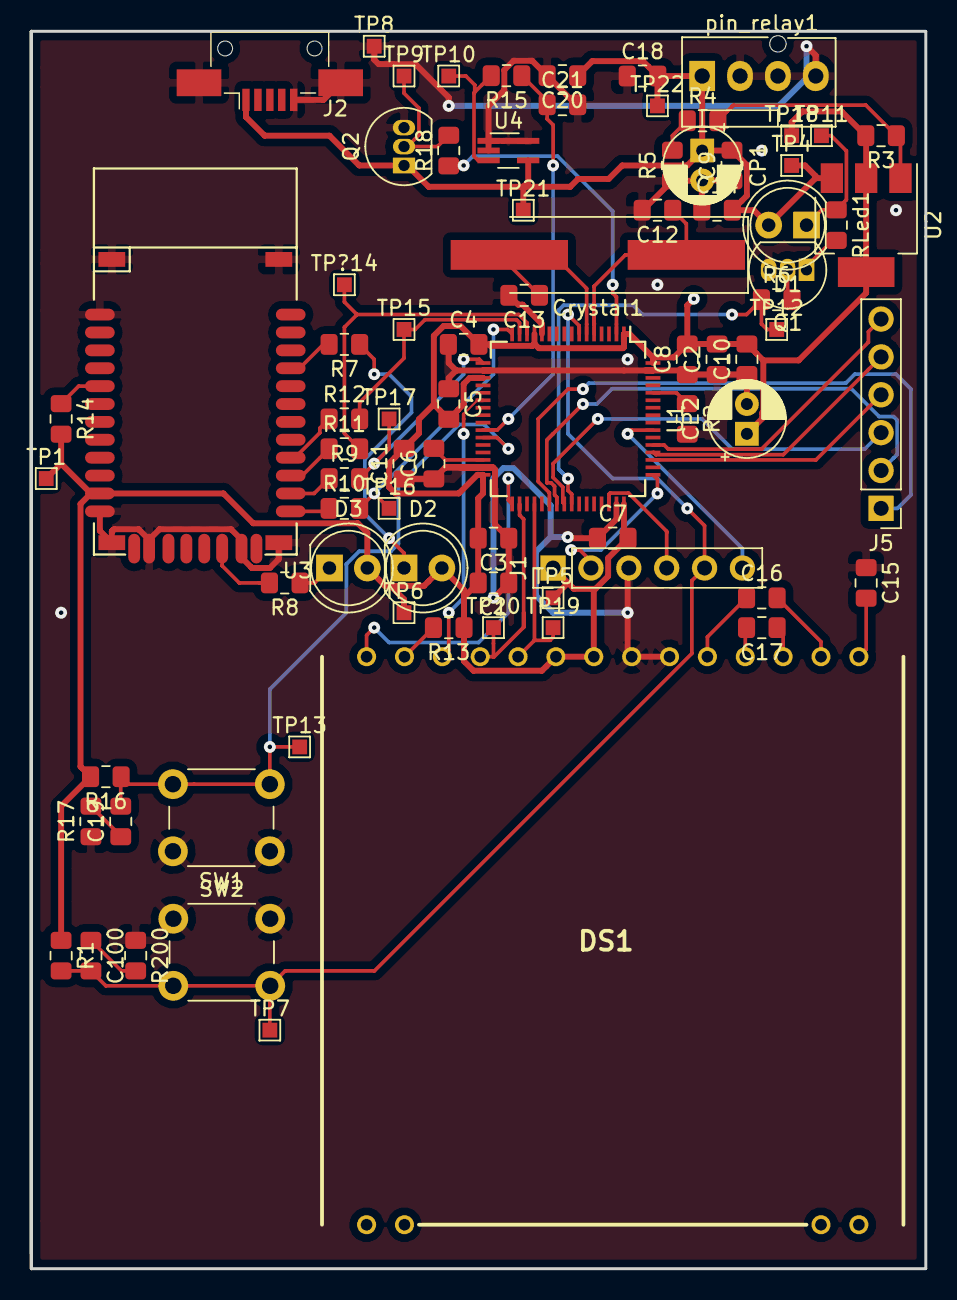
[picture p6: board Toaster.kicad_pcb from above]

Board: 2 copper layers, 60.0 x 83.0 mm, 81 parts (0 on the bottom side), 53 nets.

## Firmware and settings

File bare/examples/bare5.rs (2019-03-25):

//! bare5.rs
//!
//! C Like Peripheral API
//!
//! What it covers:
//! - abstractions in Rust
//! - structs and implementations

#![no_std]
#![no_main]

extern crate panic_halt;

extern crate cortex_m;
use cortex_m_rt::entry;

// C like API...
mod stm32f40x {
    #[allow(dead_code)]
    use core::{cell, ptr};

    #[rustfmt::skip]
    mod address {
        pub const PERIPH_BASE: u32      = 0x40000000;
        pub const AHB1PERIPH_BASE: u32  = PERIPH_BASE + 0x00020000;
        pub const RCC_BASE: u32         = AHB1PERIPH_BASE + 0x3800;
        pub const GPIOA_BASE: u32       = AHB1PERIPH_BASE + 0x0000;
    }
    use address::*;

    pub struct VolatileCell<T> {
        value: cell::UnsafeCell<T>,
    }

    impl<T> VolatileCell<T> {
        #[inline(always)]
        pub fn read(&self) -> T
        where
            T: Copy,
        {
            unsafe { ptr::read_volatile(self.value.get()) }
        }

        #[inline(always)]
        pub fn write(&self, value: T)
        where
            T: Copy,
        {
            unsafe { ptr::write_volatile(self.value.get(), value) }
        }
    }

    // modify (reads, modifies a field, and writes the volatile cell)
    //
    // parameters:
    // offset (field offset)
    // width  (field width)
    // value  (new value that the field should take)
    //
    impl VolatileCell<u32> {
        #[inline(always)]
        pub fn modify(&self, offset: u8, width: u8, value: u32) {
            let read_var = self.read();
            let bin = 0b11111111;
            let mask = !((bin << offset+width) | !(bin << offset));
            let mask_v = mask & (value << offset);
            let mod_val = (read_var & !mask) | mask_v;
            self.write(mod_val);
    
            // your code here
        }
    }

    #[repr(C)]
    #[allow(non_snake_case)]
    #[rustfmt::skip]
    pub struct RCC {
        pub CR:         VolatileCell<u32>,      // < RCC clock control register,                                    Address offset: 0x00 
        pub PLLCFGR:    VolatileCell<u32>,      // < RCC PLL configuration register,                                Address offset: 0x04 
        pub CFGR:       VolatileCell<u32>,      // < RCC clock configuration register,                              Address offset: 0x08 
        pub CIR:        VolatileCell<u32>,      // < RCC clock interrupt register,                                  Address offset: 0x0C 
        pub AHB1RSTR:   VolatileCell<u32>,      // < RCC AHB1 peripheral reset register,                            Address offset: 0x10 
        pub AHB2RSTR:   VolatileCell<u32>,      // < RCC AHB2 peripheral reset register,                            Address offset: 0x14 
        pub AHB3RSTR:   VolatileCell<u32>,      // < RCC AHB3 peripheral reset register,                            Address offset: 0x18 
        pub RESERVED0:  VolatileCell<u32>,      // < Reserved, 0x1C                                                                      
        pub APB1RSTR:   VolatileCell<u32>,      // < RCC APB1 peripheral reset register,                            Address offset: 0x20 
        pub APB2RSTR:   VolatileCell<u32>,      // < RCC APB2 peripheral reset register,                            Address offset: 0x24 
        pub RESERVED1:  [VolatileCell<u32>; 2], // < Reserved, 0x28-0x2C                                                                 
        pub AHB1ENR:    VolatileCell<u32>,      // < RCC AHB1 peripheral clock register,                            Address offset: 0x30 
        pub AHB2ENR:    VolatileCell<u32>,      // < RCC AHB2 peripheral clock register,                            Address offset: 0x34 
        pub AHB3ENR:    VolatileCell<u32>,      // < RCC AHB3 peripheral clock register,                            Address offset: 0x38 
        pub RESERVED2:  VolatileCell<u32>,      // < Reserved, 0x3C                                                                      
        pub APB1ENR:    VolatileCell<u32>,      // < RCC APB1 peripheral clock enable register,                     Address offset: 0x40 
        pub APB2ENR:    VolatileCell<u32>,      // < RCC APB2 peripheral clock enable register,                     Address offset: 0x44 
        pub RESERVED3:  [VolatileCell<u32>; 2], // < Reserved, 0x48-0x4C                                                                 
        pub AHB1LPENR:  VolatileCell<u32>,      // < RCC AHB1 peripheral clock enable in low power mode register,   Address offset: 0x50 
        pub AHB2LPENR:  VolatileCell<u32>,      // < RCC AHB2 peripheral clock enable in low power mode register,   Address offset: 0x54 
        pub AHB3LPENR:  VolatileCell<u32>,      // < RCC AHB3 peripheral clock enable in low power mode register,   Address offset: 0x58 
        pub RESERVED4:  VolatileCell<u32>,      // < Reserved, 0x5C                                                                      
        pub APB1LPENR:  VolatileCell<u32>,      // < RCC APB1 peripheral clock enable in low power mode register,   Address offset: 0x60 
        pub APB2LPENR:  VolatileCell<u32>,      // < RCC APB2 peripheral clock enable in low power mode register,   Address offset: 0x64 
        pub RESERVED5:  [VolatileCell<u32>; 2], // < Reserved, 0x68-0x6C                                                                 
        pub BDCR:       VolatileCell<u32>,      // < RCC Backup domain control register,                            Address offset: 0x70 
        pub CSR:        VolatileCell<u32>,      // < RCC clock control & status register,                           Address offset: 0x74 
        pub RESERVED6:  [VolatileCell<u32>; 2], // < Reserved, 0x78-0x7C                                                                 
        pub SSCGR:      VolatileCell<u32>,      // < RCC spread spectrum clock generation register,                 Address offset: 0x80 
        pub PLLI2SCFGR: VolatileCell<u32>,      // < RCC PLLI2S configuration register,                             Address offset: 0x84 
    }

    impl RCC {
        pub fn get() -> *mut RCC {
            address::RCC_BASE as *mut RCC
        }
    }

    #[repr(C)]
    #[allow(non_snake_case)]
    #[rustfmt::skip]
    pub struct GPIOA {
        pub MODER:      VolatileCell<u32>,      // < GPIO port mode register,                                       Address offset: 0x00     
        pub OTYPER:     VolatileCell<u32>,      // < GPIO port output type register,                                Address offset: 0x04     
        pub OSPEEDR:    VolatileCell<u32>,      // < GPIO port output speed register,                               Address offset: 0x08     
        pub PUPDR:      VolatileCell<u32>,      // < GPIO port pull-up/pull-down register,                          Address offset: 0x0C     
        pub IDR:        VolatileCell<u32>,      // < GPIO port input data register,                                 Address offset: 0x10     
        pub ODR:        VolatileCell<u32>,      // < GPIO port output data register,                                Address offset: 0x14     
        pub BSRRL:      VolatileCell<u16>,      // < GPIO port bit set/reset low register,                          Address offset: 0x18     
        pub BSRRH:      VolatileCell<u16>,      // < GPIO port bit set/reset high register,                         Address offset: 0x1A     
        pub LCKR:       VolatileCell<u32>,      // < GPIO port configuration lock register,                         Address offset: 0x1C     
        pub AFR:        [VolatileCell<u32>;2],  // < GPIO alternate function registers,                             Address offset: 0x20-0x24
    }

    impl GPIOA {
        pub fn get() -> *mut GPIOA {
            GPIOA_BASE as *mut GPIOA
        }
    }
}
use stm32f40x::*;

// see the Reference Manual RM0368 (www.st.com/resource/en/reference_manual/dm00096844.pdf)
// rcc,     chapter 6
// gpio,    chapter 8

fn wait(i: u32) {
    for _ in 0..i {
        cortex_m::asm::nop(); // no operation (cannot be optimized out)
    }
}


// simple test of Your `modify`
fn test() {
    let t:VolatileCell<u32> = unsafe {  core::mem::uninitialized() };
    t.write(0);
    assert!(t.read() == 0);
    t.modify(3, 3, 0b10101);
//
//     10101
//    ..0111000
//    ---------
//    000101000
    assert!(t.read() == 0b101 << 3);
    t.modify(4, 3, 0b10001);
//    000101000
//      111
//      001
//    000011000
    assert!(t.read() == 0b011 << 3);

// if << is used, your code will panic in dev (debug), but not in release mode
    t.modify(32, 3, 1);
}

// system startup, can be hidden from the user
#[entry]
fn main() -> ! {
    let rcc = unsafe { &mut *RCC::get() }; // get the reference to RCC in memory
    let gpioa = unsafe { &mut *GPIOA::get() }; // get the reference to GPIOA in memory

    test(); // uncomment to run test
    idle(rcc, gpioa);
    loop {}
}

// user application
fn idle(rcc: &mut RCC, gpioa: &mut GPIOA) {
    // power on GPIOA
    //let r = rcc.AHB1ENR.read(); // read
    //rcc.AHB1ENR.write(r | 1 << (0)); // set enable
    rcc.AHB1ENR.modify(0, 1, 0b1);

    // configure PA5 as output
    gpioa.MODER.modify(5*2, 2, 0b01);
    //let r = gpioa.MODER.read() & !(0b11 << (5 * 2)); // read and mask
    //gpioa.MODER.write(r | 0b01 << (5 * 2)); // set output mode

    loop {
        // set PA5 high
        //gpioa.BSRRH.write(1 << 5); // set bit, output hight (turn on led)
        //gpioa.ODR.write(gpioa.ODR.read() | (1 << 5));
        gpioa.ODR.modify(5, 1, 0b1);
        wait(100_000);
        //wait(10_000);

        // set PA5 low
        //gpioa.BSRRL.write(1 << 5); // clear bit, output low (turn off led)
        //gpioa.ODR.write(gpioa.ODR.read() & !(1 << 5));
        gpioa.ODR.modify(5, 1, 0b0);
        wait(100_000);
        //wait(10_000);
    }
}

// 0. Build and run the application.
//
//    > cargo build --example bare5
//    (or use the vscode build task)
//
// 1. C like API.
//    In C the .h files are used for defining interfaces, like function signatures (prototypes),
//    structs and macros (but usually not the functions themselves).
//
//    Here is a peripheral abstraction quite similar to what you would find in the .h files
//    provided by ST (and other companies). Actually, the file presesnted here is mostly a
//    cut/paste/replace of the stm32f40x.h, just Rustified.
//
//    In this case we pass mutable pointers of the peripherals to the `idle` function.
//
//    In the loop we access PA5 through bit set/clear operations.
//    Comment out those opertations and uncomment the the ODR accesses.
//    (They should have the same behavior, but is a bit less efficient.)
//
//    Run and see that the program behaves the same.
//    It behaves the same, lamp is flashing like before.
//
//    Commit your answers (bare5_1)
//
// 2. Extend the read/write API with a modify for u32, taking the
//    - address (&mut u32),
//    - field offset (in bits, u8),
//    - field width (in bits, u8),
//    - and value (u32).
//
//    Implement and check that running `test` gives you expected behavior.
//
//    Change the code into using your new API.
//
//    Run and see that the program behaves the same.
//  
//    
//    Commit your answers (bare5_2)
//
//    Discussion:
//    As with algebraic operations, defalut semantics differ in between
//    debug/dev and release builds. E.g., debug << rhs is checked, rhs must be less
//    than 32 (for 32 bit datatypes).
//
//    Notice, over-shifting (where bits are spilled) is always considered legal,
//    its just the shift amuount that is checked.
//    There are explicit unchecked versions available if so wanted.

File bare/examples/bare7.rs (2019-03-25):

//! bare7.rs
//! 
//! Serial echo
//!
//! What it covers:
//! - changing the clock using Rust code
//! - working with the svd2rust API
//! - working with the HAL (Hardware Abstraction Layer)
//! - USART polling (blocking wait)

#![deny(unsafe_code)]
#![no_main]
#![no_std]

extern crate panic_halt;

use cortex_m::iprintln;
use cortex_m_rt::entry;
use nb::block;

extern crate stm32f4xx_hal as hal;
use crate::hal::prelude::*;
use crate::hal::serial::{config::Config, Serial};
use stm32f4xx_hal::stm32::{self, DWT, GPIOA, GPIOC, RCC};

#[entry]
fn main() -> ! {
    let mut c = hal::stm32::CorePeripherals::take().unwrap();
    let stim = &mut c.ITM.stim[0];
    iprintln!(stim, "bare7");

    let p = hal::stm32::Peripherals::take().unwrap();

    let rcc = p.RCC.constrain();

    // 16 MHz (default, all clocks)
    let clocks = rcc.cfgr.sysclk(84.mhz()).hclk(84.mhz()).pclk1(42.mhz()).pclk2(64.mhz()).freeze();

    let gpioa = p.GPIOA.split();

    let tx = gpioa.pa2.into_alternate_af7();
    let rx = gpioa.pa3.into_alternate_af7(); // try comment out
    // let rx = gpioa.pa3.into_alternate_af6(); // try uncomment

    let serial = Serial::usart2(
        p.USART2,
        (tx, rx),
        Config::default().baudrate(115_200.bps()),
        clocks,
    )
    .unwrap();

    // Separate out the sender and receiver of the serial port
    let (mut tx, mut rx) = serial.split();
    let gpioc = p.GPIOC.split();
    gpioc.pc9.into_alternate_af0().set_speed(hal::gpio::Speed::Low);

    loop {
        match block!(rx.read()) {
            Ok(byte) => {
                iprintln!(stim, "Ok {:?}", byte);
                tx.write(byte).unwrap(); 
            }
            Err(err) => {
                iprintln!(stim, "Error {:?}", err);
            }
        }
    }

}

// 0. Background reading:
//    STM32F401xD STM32F401xE, section 3.11
//    We have two AMBA High-performance Bus (AHB)
//    APB1 low speed bus (max freq 42 MHz)
//    APB2 high speed bus (max frex 84 MHz)
//
//    RM0368 Section 6.2
//    Some important/useful clock acronymes and their use:
//
//    SYSCLK - the clock that drives the `core`
//    HCLK   - the clock that drives the AMBA bus(es), memory, DMA, trace unit, etc.
//
//    Typically we set HCLK = SYSCLK / 1 (no prescale) for our applications
//
//    FCLK   - Free running clock runing at HCLK
//
//    CST    - CoreSystemTimer drives the SysTick counter, HCLK/(1 or 8)
//    PCLK1  - The clock driving the APB1 (<= 42 MHz)
//             Timers on the APB1 bus will be triggered at PCLK1 * 2
//    PCLK2  - The clock driving the APB2 (<= 84 MHz)
//             Timers on the APB2 bus will be triggered at PCLK2
//
//    Compliation:
//    > cargo build --example bare7 --features "hal"
//    (or use the vscode build task)
//
//    The "hal" feature enables the optional dependency stm32f4xx-hal".
//
//    Cargo.toml:
// 
//    [dependencies.stm32f4]
//    version = "0.5.0"
//    features = ["stm32f413", "rt"]
//    optional = true
// 
//    [dependencies.stm32f4xx-hal]
//    git = "https://github.com/stm32-rs/stm32f4xx-hal.git"
//    version = "0.2.8"
//    features = ["stm32f413", "rt"]
//    optional = true
//
//    [features]
//    pac = ["stm32f4"]
//    hal = ["stm32f4xx-hal"]
//
//    Notice, stm32f4xx-hal internally enables the dependency to stm32f4, 
//    so we don't need to explicitly enable it.
//
//    The HAL provides a generic abstraction over the whole stm32f4 family,
//    as previously we use the stm32f413, since it also covers stm32f401/stm32f411.
//
// 1. The rcc.cfgr.x.freeze() sets the clock according to the configuration x given.
//
//    rcc.cfgr.freeze(); sets a default configuration.
//    sysclk = hclk = pclk1 = pclk2 = 16MHz
//
//    What is wrong with the following configurations?
//
//    rcc.cfgr.sysclk(64.mhz()).pclk1(64.mhz()).pclk2(64.mhz()).freeze();
//
//    The max frequency for pclk1 is 42MHz so it won't work with specified 64.
//    HCLK should be set to 64MHz alsongside the sysclk. Above config will set it to default 16MHz which is wrong.
//
//    rcc.cfgr.sysclk(84.mhz()).pclk1(42.mhz()).pclk2(64.mhz()).freeze();
//
//    hclk needs to be set to 84MHz.
//
//    Commit your answers (bare7_1)
//
//    Tip: You may use `stm32cubemx` to get a graphical view for experimentation.
//    This is a good tool when designing your PCB (as pinouts are given).
//
// 2. Now give the system with a valid clock, sysclk of 84 MHz.
//
//    Include the code for outputting the clock to MCO2.
//
//    Repeat the expermient bare6_2.
//
//    What is the frequency of MCO2 read by the oscilloscope.
//
//    84MHz
//
//    Compute the value of SYSCLK based on the oscilloscope reading.
//
//    84MHz as specified in the code
//
//    What is the peak to peak reading of the signal.
//
//    10.1V
//
//    Make a screen dump or photo of the oscilloscope output.
//    Save the the picture as "bare_6_84mhz_high_speed"
//
//    Commit your answers (bare7_2)
//
// 3. Now reprogram the PC9 to be "Low Speed", and re-run at 84Mz.
//
//    Did the frequency change in comparison to assignment 5?
//
//    Unreadable it changed a lot. Only says "no edges"
//
//    What is the peak to peak reading of the signal (and why did it change)?
//
//    peak is 70mV since the signal is so low the peak to peak reading will be almost non-existant as well.
//
//    Make a screen dump or photo of the oscilloscope output.
//    Save the the picture as "bare_6_84mhz_low_speed".
//
//    Commit your answers (bare7_3)
//
// 4. Revisit the `README.md` regarding serial communication.
//    start a terminal program, e.g., `moserial`.
//    Connect to the port
//
//    Device       /dev/ttyACM0
//    Baude Rate   115200
//    Data Bits    8
//    Stop Bits    1
//    Parity       None
//    
//    This setting is typically abbreviated as 115200 8N1.
//
//    Run the example, make sure your ITM is set to 84MHz.
//
//    Send a single character (byte), (set the option No end in moserial).
//    Verify that sent bytes are echoed back, and that ITM tracing is working.
// 
//    If not go back check your ITM setting, clocks etc.
//
//    Try sending: "abcd" as a single sequence, don't send the quation marks, just abcd.
//
//    What did you receive, and what was the output of the ITM trace.
//
//    I recieve a neverending stream of abcdabcdabcdabcd etc..
//    The ITM trace outputs ok 97, ok 98, ok 99, ok 100 in a loop as well.
//
//    Explain why the buffer overflows.
//
//    It does not overflow, if it were to overflow it would be because it is trying to write bytes before the buffer could reset.
//
//    commit your answers (bare7_4)
//
//    Discussion:
//    Common to all MCUs is that they have multiple clocking options.
//    Understanding the possibilities and limitations of clocking is fundamental
//    to designing both the embedded hardware and software. Tools like
//    `stm32cubemx` can be helpful to give you the big picture.
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

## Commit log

2019-03-25 removed dirs for Lucas
    [_saved_test.sch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]
2019-03-25 added bare again
    [stlink.cfg, stm32f4x.cfg]
2019-03-25 added the temp-sensor code example
    [stlink.cfg, stm32f4x.cfg]
2019-03-26 added temperature sensor conversion
2019-03-26 added temperature estimate
2019-03-26 Edited BT section, added temp sens and adc section
2019-04-02 started refzctoring spiTest into pcbProject
2019-04-15 Update pcbProject.rs
    Now fills half the screen during the screen paint animation
2019-05-12 Fixed usart2, cand send and receive via bluetooth
    [pcb_project.rs]

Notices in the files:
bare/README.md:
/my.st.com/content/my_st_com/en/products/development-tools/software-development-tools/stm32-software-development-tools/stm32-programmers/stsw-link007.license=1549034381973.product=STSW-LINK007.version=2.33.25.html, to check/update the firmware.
